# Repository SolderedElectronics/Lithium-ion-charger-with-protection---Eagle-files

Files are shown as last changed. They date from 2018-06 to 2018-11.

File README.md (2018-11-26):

# Lithium-ion battery charger with protection - Eagle Files
## Image
charger image
[Lithium-ion battery charger with protection(222007)](https://e-radionica.com/hr/li-ion-punjac-s-zastitom-jst.html)

## Description and details
Since lithium batteries demand a special charging regime, and you must not charge them on a regular power source, you will need a charger like this one. Affordable, with integrated CC/CV charging regime, definitely the easiest way to charge some lithium batteries. Input voltage is connectable via USB cables or separate terminals. In addition, this charger includes battery protection which means that your cell (18650 battery for example) is protected from overvoltage, undervoltage and a large short circuit current.

- Input voltage: 4.5V-5.5V
- Output max. current: 1A, adjustable
- A voltage at which the charging stops: 4.2V
- Two LED diodes, red diode signals charging, green diode signals full battery
- With short circuit, overvoltage and undervoltage protection!
- Without reverse polarity protection on input!

## Repository content
This repo contains Cadsoft Eagle .sch and .brd files for Croduino Basic board. It also contains schematic in .pdf created from .sch Eagle file. 
Files have been arranged into folders for navigating between different versions of board. 
Tip: layer 200 shows top silkscreen and layer 208 should be bottom silkscreen. tParts and bParts is not used.

## Docs
- [Lithium-ion battery charger with protection] (https://e-radionica.com/hr/li-ion-punjac-s-zastitom-jst.html)

## Board versions
- v1.0 - inital version

## License info
This product is open-source. Yay!
For any tech questions, contact us at techsupport@e-radionica.com
If you find an Issue, please open one at GitHub. If you can improve our product, fork us.

e-radionica.com Team.

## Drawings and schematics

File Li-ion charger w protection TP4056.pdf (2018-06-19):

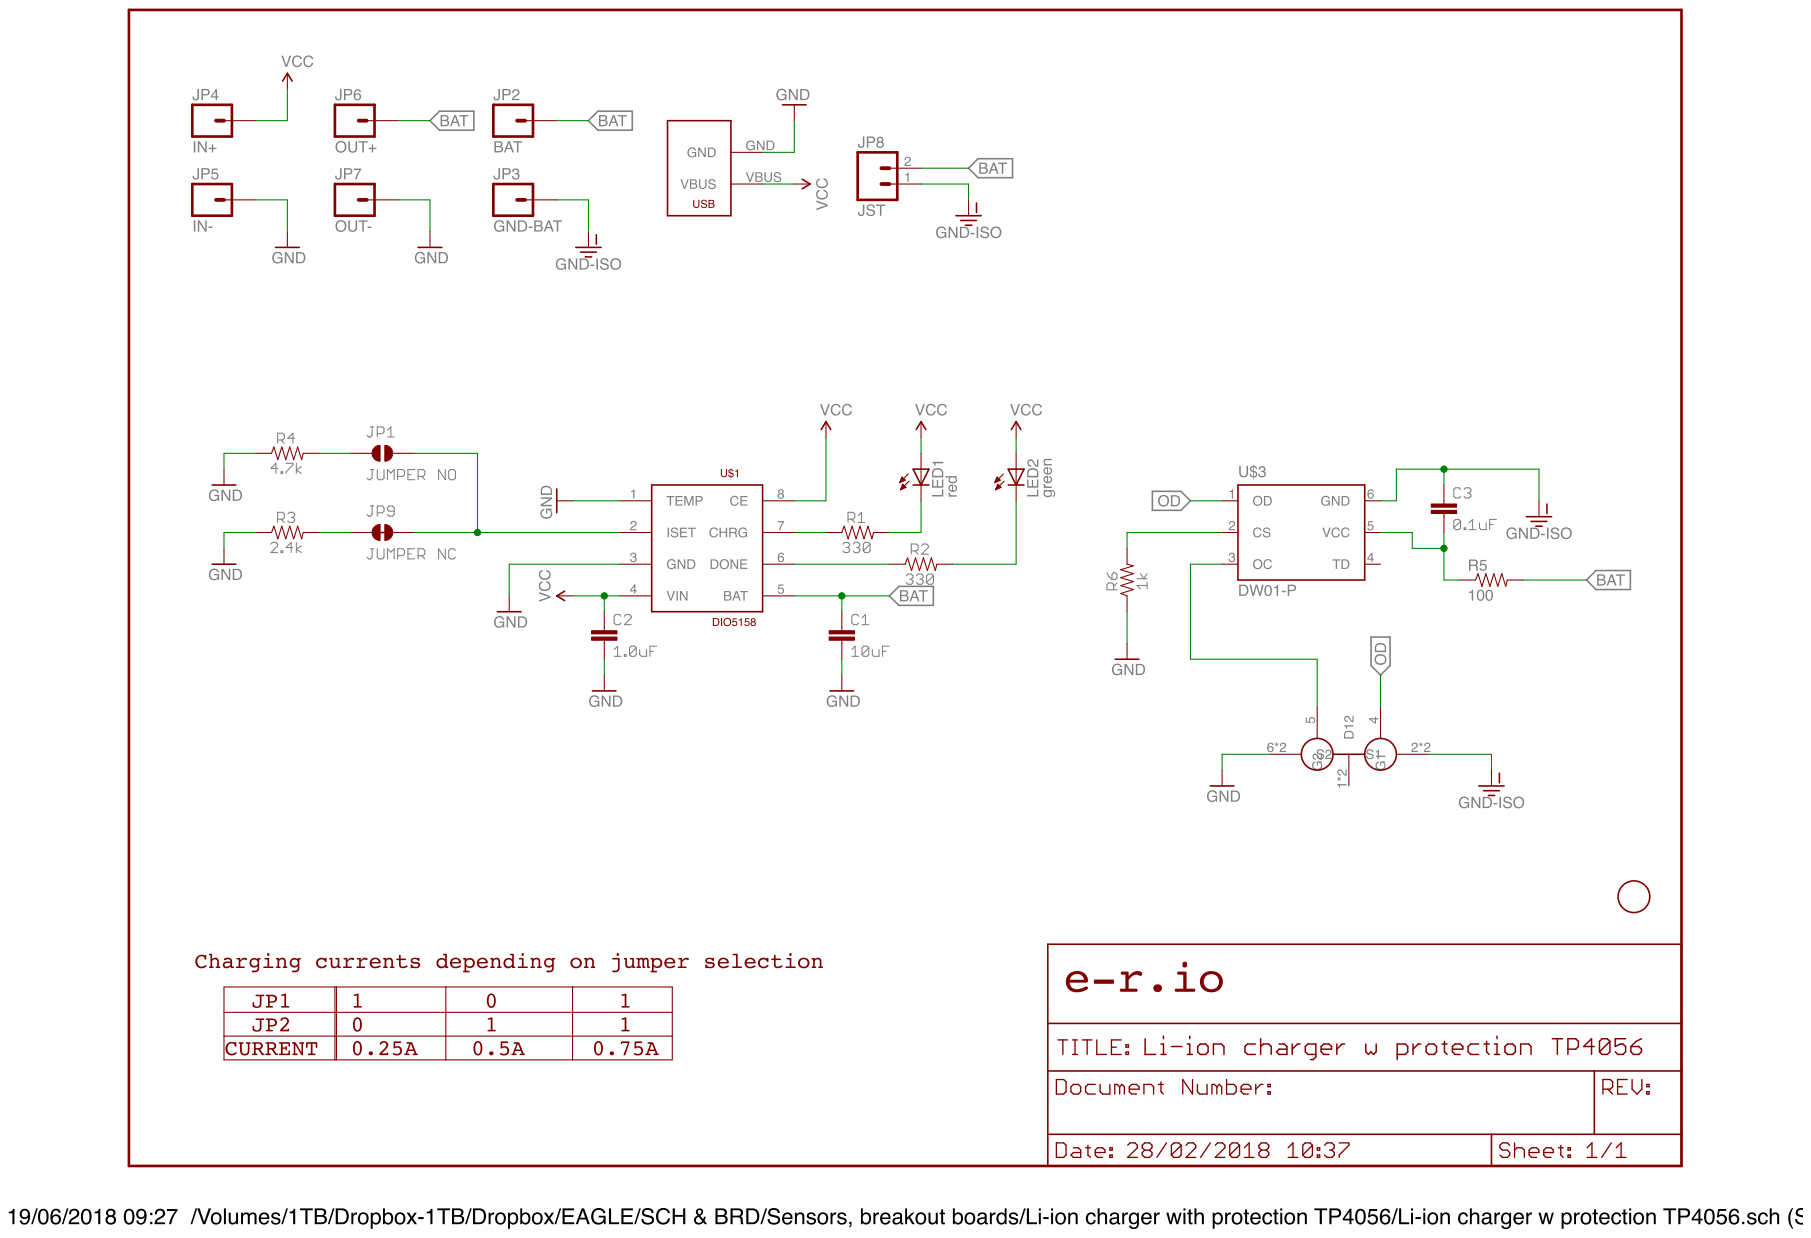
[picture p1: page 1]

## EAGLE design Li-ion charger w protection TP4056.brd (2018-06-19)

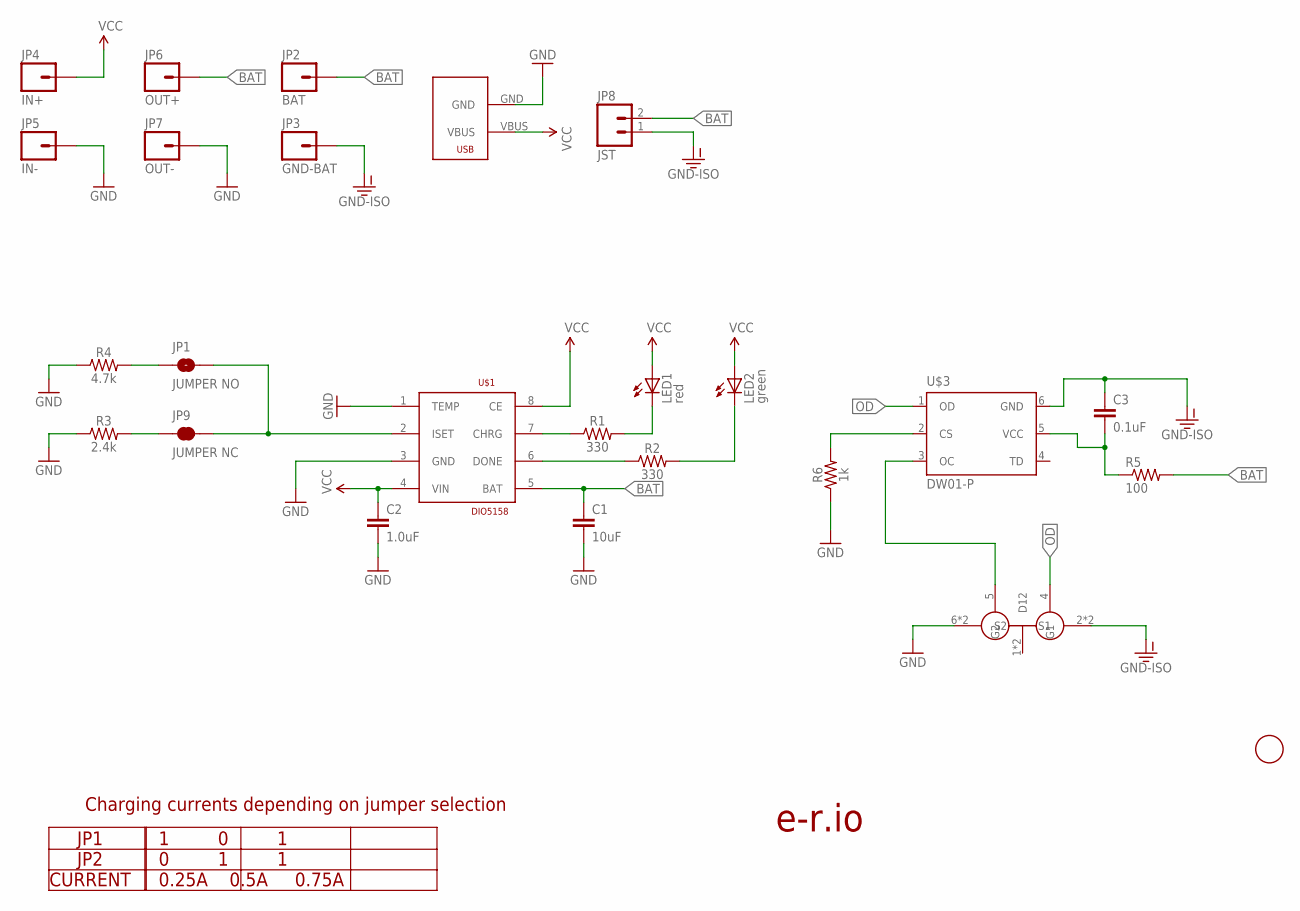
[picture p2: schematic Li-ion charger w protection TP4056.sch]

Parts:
C1: 10uF; 1206
C2: 1.0uF; 0603
C3: 0.1uF; 0603
JP1: JUMPER NO; SMT-JUMPER_2_NO_NO-SILK
JP2: BAT; 1X01
JP3: GND-BAT; 1X01
JP4: IN+; 1X01
JP5: IN-; 1X01
JP6: OUT+; 1X01
JP7: OUT-; 1X01
JP8: JST; JST-2-SMD
JP9: JUMPER NC; SMT-JUMPER_2_NC_TRACE_NO-SILK
LED1: red; CHIP-LED0805
LED2: green; CHIP-LED0805
R1, R2: 330; 0603
R3: 2.4k; 0603
R4: 4.7k; 0603
R5: 100; 0603-RES
R6: 1k; 0603
U$1: DIO5158; SOIC-8
U$2: FIDUCIAL; FIDUCIAL_1MM
U$3: DW01-P; SOT23-6L
U$4: FS8205A; TSSOP8
U$5: USB-MICROB-POWERONLY

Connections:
BAT: C1.1, JP2.1, JP6.1, JP8.2, R5.2, U$1.5 (BAT)
CHRG: R1.1, U$1.7 (CHRG)
DONE: R2.1, U$1.6 (DONE)
GND: C1.2, C2.2, JP5.1, JP7.1, R3.1, R4.1, R6.1, U$1.1 (TEMP), U$1.3 (GND), U$4.6 (S2), U$4.7 (S2), U$5.GND
GND-ISO: C3.1, JP3.1, JP8.1, U$3.6 (GND), U$4.2 (S1), U$4.3 (S1)
ISET: JP1.2, JP9.2, U$1.2 (ISET)
LED1: LED1.C, R1.2
LED2: LED2.C, R2.2
unnamed: R6.2, U$3.2 (CS)
unnamed: U$3.3 (OC), U$4.5 (G2)
unnamed: JP9.1, R3.2
unnamed: JP1.1, R4.2
OD: U$3.1 (OD), U$4.4 (G1)
VCC: C2.1, JP4.1, LED1.A, LED2.A, U$1.4 (VIN), U$1.8 (CE), U$5.VBUS
VCC-DW: C3.2, R5.1, U$3.5 (VCC)

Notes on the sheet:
JP1 JP2 CURRENT
1 0 1 0 1 1 0.25A 0.5A 0.75A
Charging currents depending on jumper selection
e-r.io

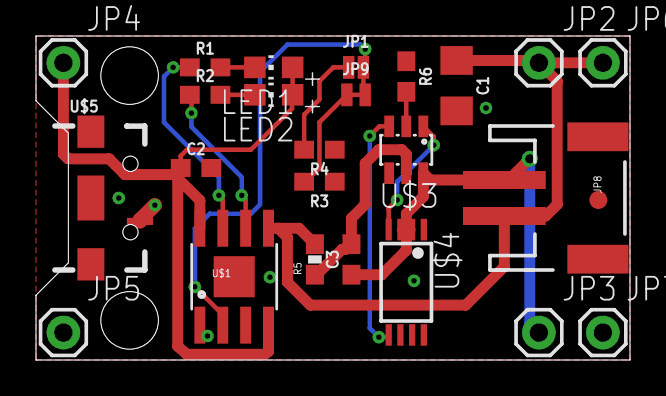
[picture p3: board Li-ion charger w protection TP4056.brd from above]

Board: 2 copper layers, 33.0 x 18.0 mm, 30 parts (0 on the bottom side), 15 nets.

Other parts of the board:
U$6: LOGO-3MM
U$7: E-R.IO-3MM
U$8: OSH-3MM
U$9: LOGO-BACK-6MM
U$10: E-R.IO-BACK-6MM

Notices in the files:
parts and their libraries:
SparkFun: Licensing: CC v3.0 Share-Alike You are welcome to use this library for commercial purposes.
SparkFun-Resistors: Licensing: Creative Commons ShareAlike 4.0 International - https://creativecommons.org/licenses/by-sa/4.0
